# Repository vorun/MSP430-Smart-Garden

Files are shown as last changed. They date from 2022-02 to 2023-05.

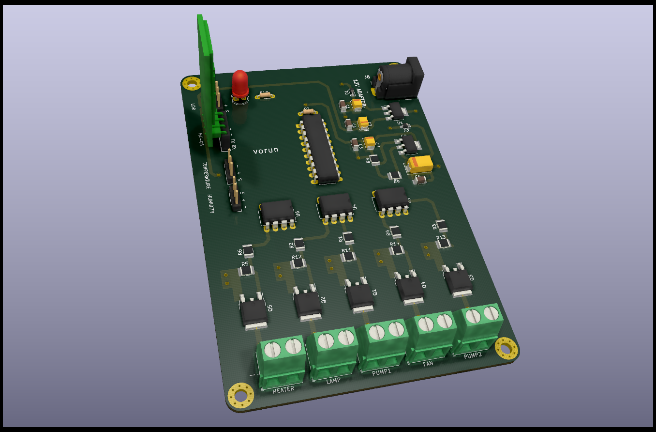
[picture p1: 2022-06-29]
PCB 3D View.png

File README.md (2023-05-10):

# MSP430-Smart-Garden

This project is a smart agricultural system based on C# using MSP430 microcontroller.

- Data coming from 3 sensors gets sent serially using bluetooth module from msp430 to computer and displayed at the
screen.

- Devices connected to msp430 which are lamp, fan, heater and 2 water pumps can be controlled from the
computer. Each button sends a different character and msp430 does operations acording to character it 
receives. Msp430 generates 3 different pwm signals to control fan and lamp for each setting which are 
low, medium and high. Heater can be oppened and closed. 2 water pumps can be oppened for 3 different 
amount times which are 3 seconds, 7 seconds and 10 seconds.

- Pin connections and circuit design/PCB of the project can be found at the 
"C# Based Smart Gardener Final PCB" folder.

For demo: https://www.youtube.com/watch?v=NzMayukbllw

Note
- Updated PCB with MOSFETs and gate drivers.

Orhun Dabak/Ahmet Özbaysar
PCB 3D View (1)
Picture_C#

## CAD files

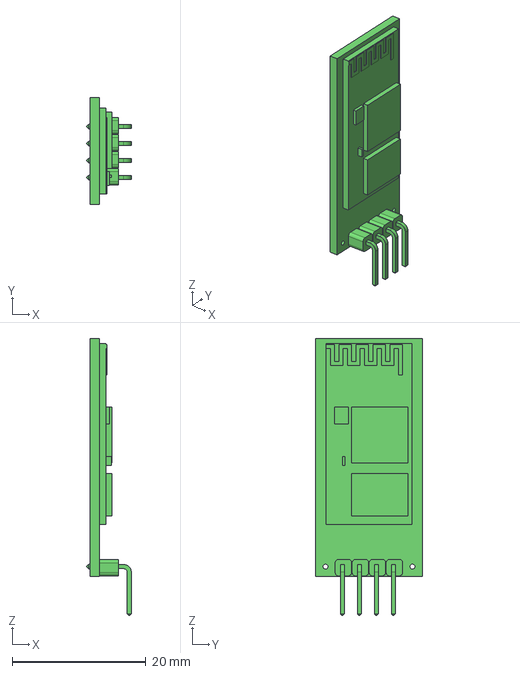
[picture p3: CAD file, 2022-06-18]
C# Based Smart Gardener Final PCB/hc 05/HC-05 Bluetooth Module.stp
6.68 x 16.0 x 41.4 mm

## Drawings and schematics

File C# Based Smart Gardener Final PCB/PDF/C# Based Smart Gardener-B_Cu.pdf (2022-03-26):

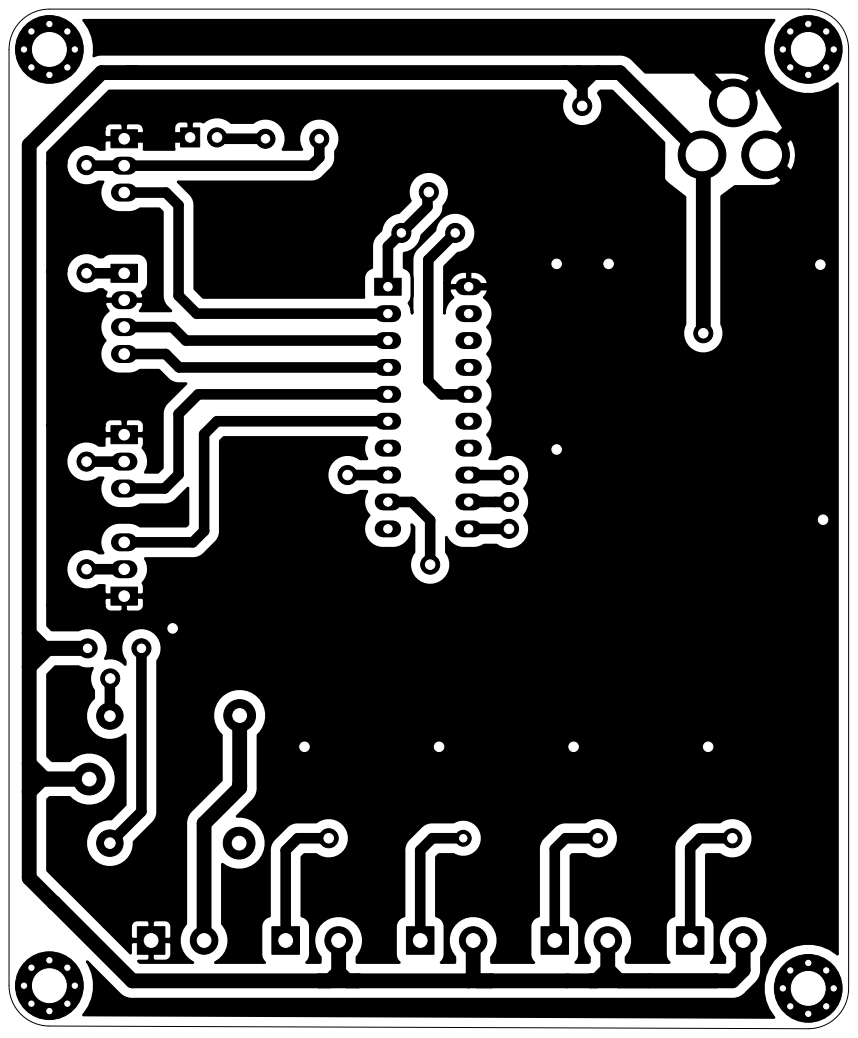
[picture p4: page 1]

File: C# Based Smart Gardener.kicad_pcb Sheet:
Id: 1/1 Title:

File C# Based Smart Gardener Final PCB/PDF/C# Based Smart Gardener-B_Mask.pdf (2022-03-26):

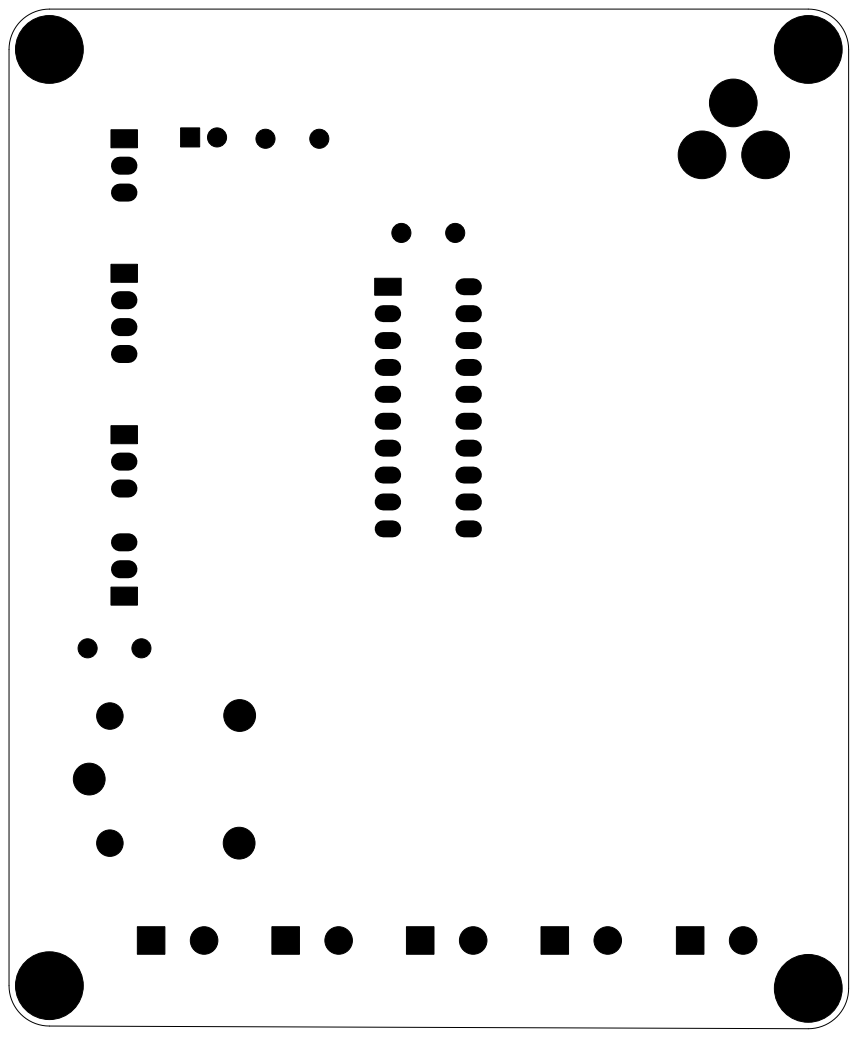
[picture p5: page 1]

File: C# Based Smart Gardener.kicad_pcb Sheet:
Id: 1/1 Title:

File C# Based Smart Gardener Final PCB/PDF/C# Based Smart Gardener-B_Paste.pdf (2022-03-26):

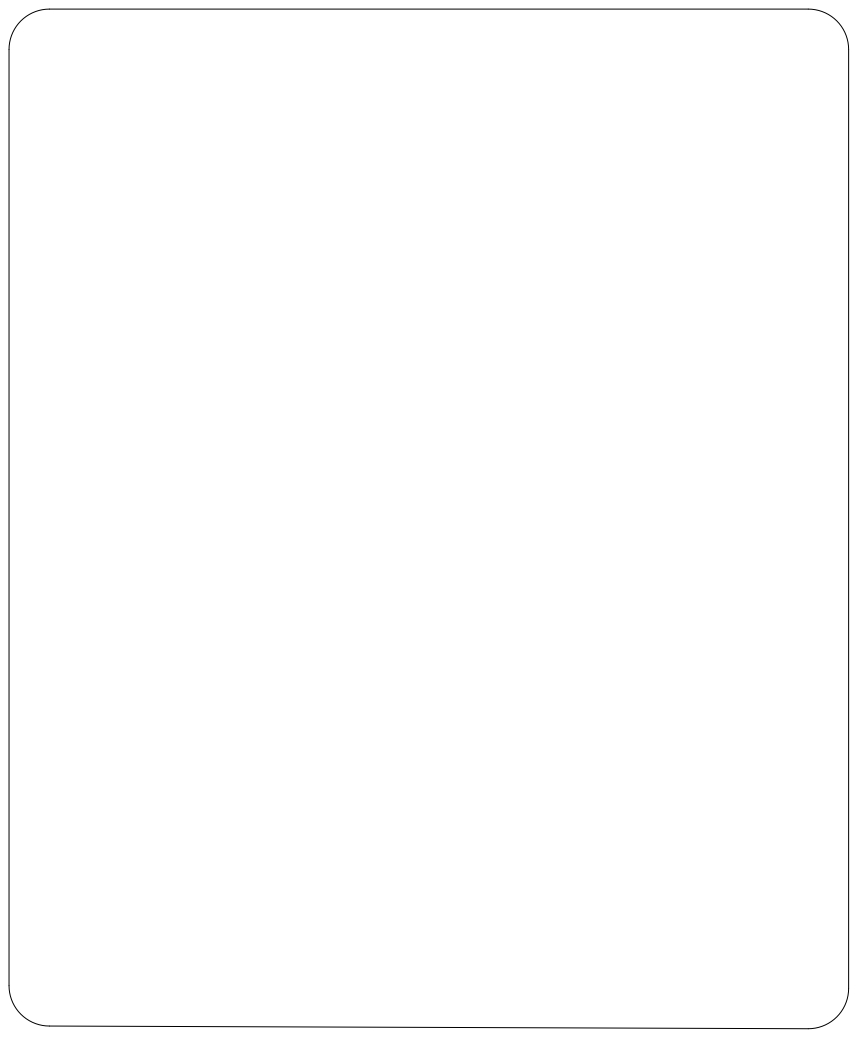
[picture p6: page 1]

File: C# Based Smart Gardener.kicad_pcb Sheet:
Id: 1/1 Title:

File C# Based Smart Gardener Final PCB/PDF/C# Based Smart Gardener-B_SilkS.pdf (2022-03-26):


File: C# Based Smart Gardener.kicad_pcb Sheet:
Id: 1/1 Title:

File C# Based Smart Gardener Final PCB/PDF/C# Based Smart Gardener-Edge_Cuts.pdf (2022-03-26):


File: C# Based Smart Gardener.kicad_pcb Sheet:
Id: 1/1 Title:

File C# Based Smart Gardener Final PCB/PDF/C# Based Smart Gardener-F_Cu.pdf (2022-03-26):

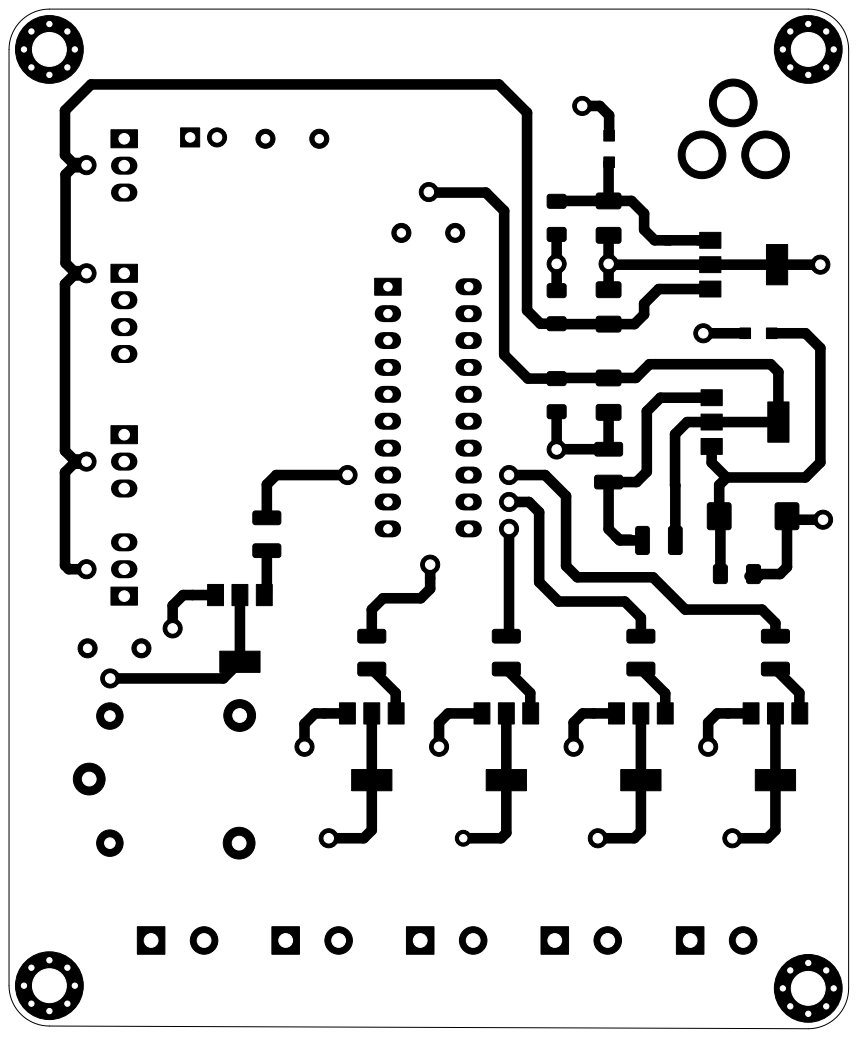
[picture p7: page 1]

File: C# Based Smart Gardener.kicad_pcb Sheet:
Id: 1/1 Title:

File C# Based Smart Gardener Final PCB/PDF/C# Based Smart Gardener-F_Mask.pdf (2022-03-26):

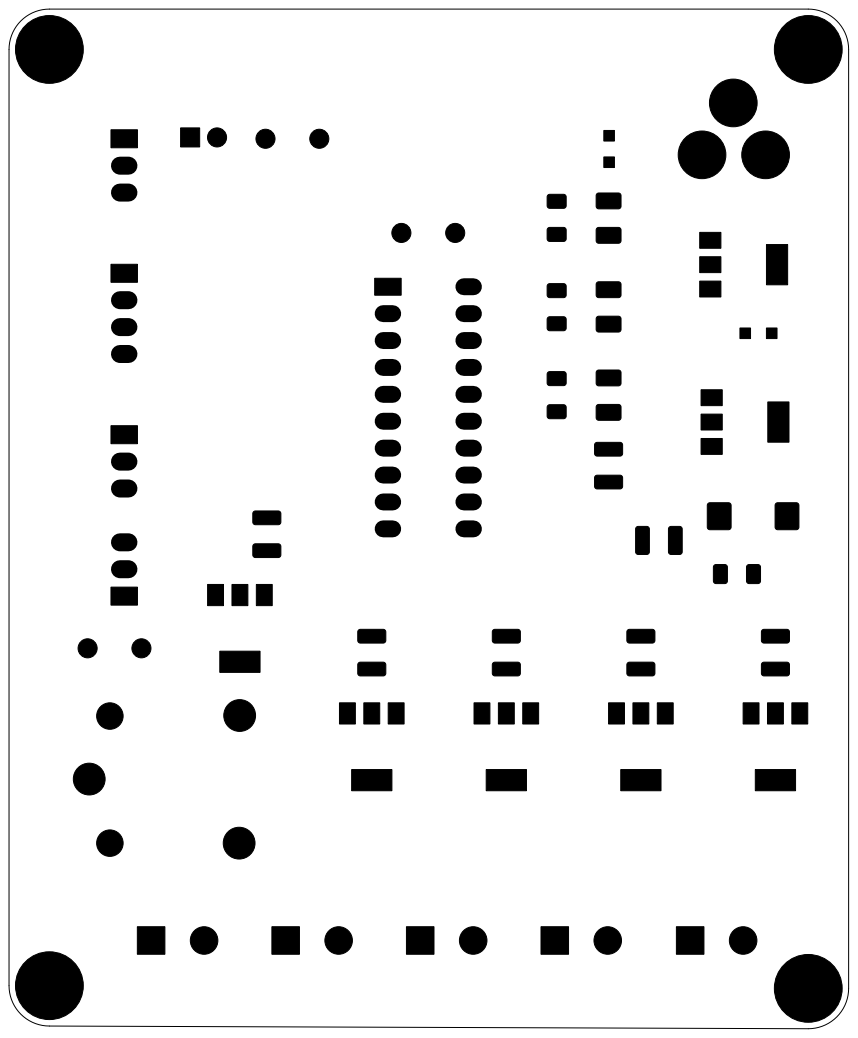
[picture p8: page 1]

File: C# Based Smart Gardener.kicad_pcb Sheet:
Id: 1/1 Title:

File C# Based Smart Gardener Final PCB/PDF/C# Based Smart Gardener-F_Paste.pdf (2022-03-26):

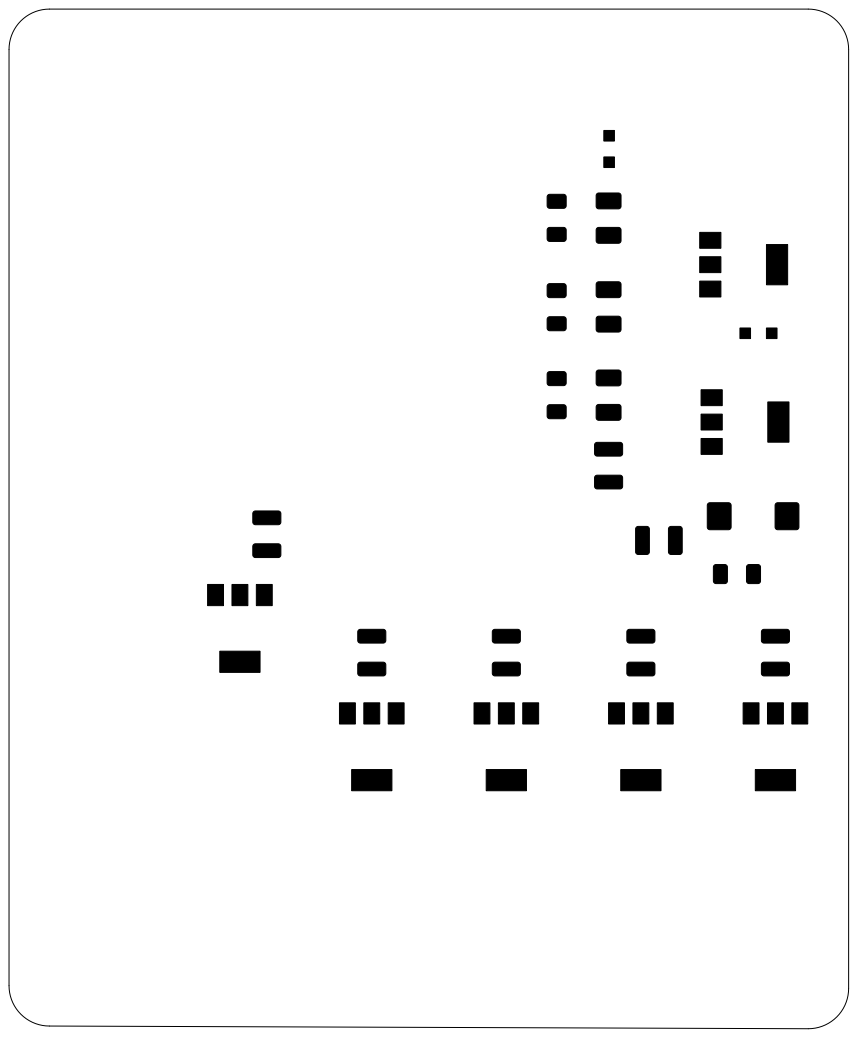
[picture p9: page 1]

File: C# Based Smart Gardener.kicad_pcb Sheet:
Id: 1/1 Title:

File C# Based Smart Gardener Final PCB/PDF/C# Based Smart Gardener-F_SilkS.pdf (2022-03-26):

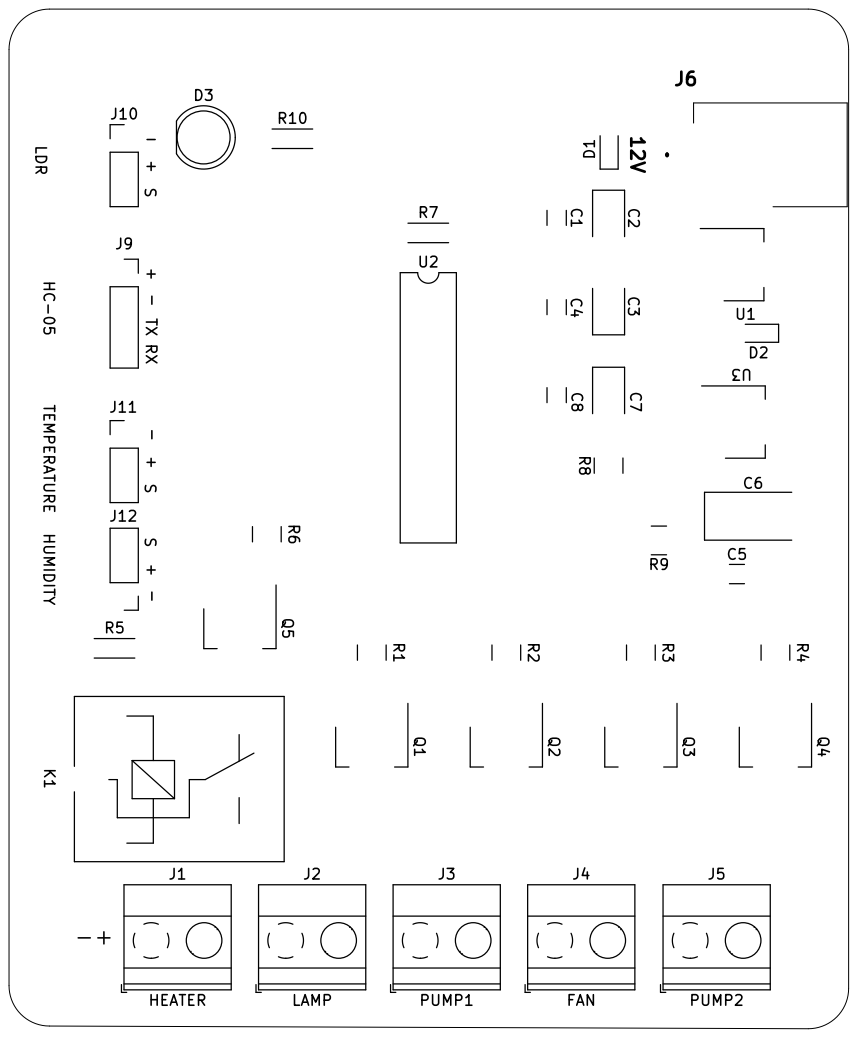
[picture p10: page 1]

File: C# Based Smart Gardener.kicad_pcb Sheet: - +S S +- - TX RX +S -+

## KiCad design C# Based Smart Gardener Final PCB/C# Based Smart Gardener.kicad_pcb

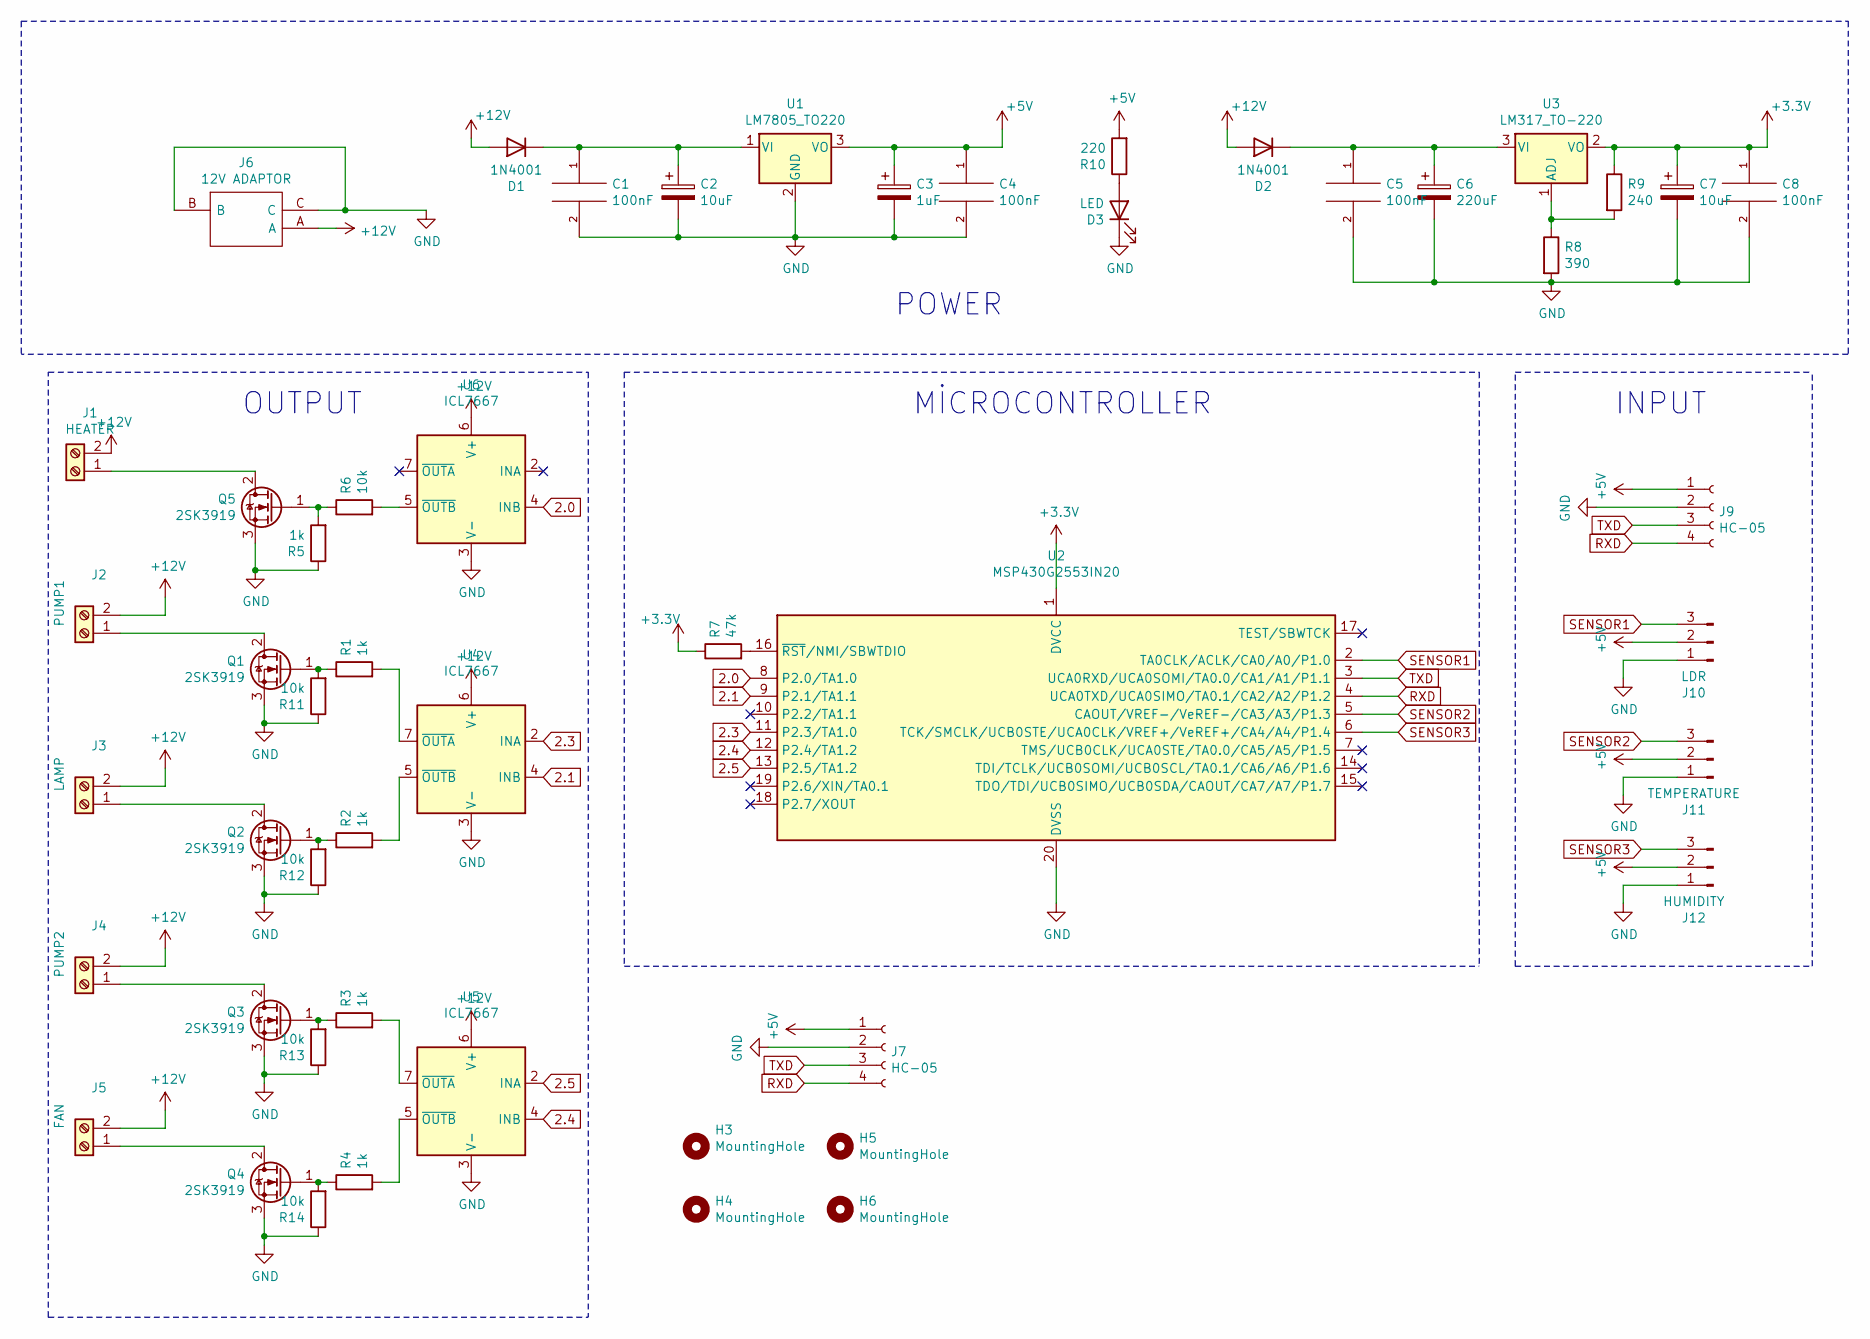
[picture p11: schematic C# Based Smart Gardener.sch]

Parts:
C1, C4, C5, C8: 100nF; C_1206_3216Metric_Pad1.33x1.80mm_HandSolder
C2, C7: 10uF; CP_EIA-3528-21_Kemet-B_Pad1.50x2.35mm_HandSolder
C3: 1uF; CP_EIA-3528-21_Kemet-B_Pad1.50x2.35mm_HandSolder
C6: 220uF; CP_EIA-7343-31_Kemet-D_Pad2.25x2.55mm_HandSolder
D1, D2: 1N4001; D_SOD-323_HandSoldering
D3: LED; LED_D5.0mm
H3, H4, H5, H6: MountingHole; MountingHole_3.2mm_M3_Pad_Via
J1: HEATER; TerminalBlock_Phoenix_MKDS-1,5-2_1x02_P5.00mm_Horizontal
J2: PUMP1; TerminalBlock_Phoenix_MKDS-1,5-2_1x02_P5.00mm_Horizontal
J3: LAMP; TerminalBlock_Phoenix_MKDS-1,5-2_1x02_P5.00mm_Horizontal
J4: PUMP2; TerminalBlock_Phoenix_MKDS-1,5-2_1x02_P5.00mm_Horizontal
J5: FAN; TerminalBlock_Phoenix_MKDS-1,5-2_1x02_P5.00mm_Horizontal
J6: 12V ADAPTOR; 163179PHEX; Manufacturer_Part_Number 163-179PH-EX; Mouser Part Number 163-179PH-EX
J7, J9: HC-05; PinSocket_1x04_P2.54mm_Vertical
J10: LDR; PinHeader_1x03_P2.54mm_Vertical
J11: TEMPERATURE; PinHeader_1x03_P2.54mm_Vertical
J12: HUMIDITY; PinHeader_1x03_P2.54mm_Vertical
Q1, Q2, Q3, Q4, Q5: 2SK3919; TO-252-2
R1, R2, R3, R4, R5: 1k; R_1210_3225Metric_Pad1.30x2.65mm_HandSolder
R6, R11, R12, R13, R14: 10k; R_1210_3225Metric_Pad1.30x2.65mm_HandSolder
R7: 47k; R_Axial_DIN0204_L3.6mm_D1.6mm_P5.08mm_Horizontal
R8: 390; R_1210_3225Metric_Pad1.30x2.65mm_HandSolder
R9: 240; R_1210_3225Metric_Pad1.30x2.65mm_HandSolder
R10: 220; R_Axial_DIN0204_L3.6mm_D1.6mm_P5.08mm_Horizontal
U1: LM7805_TO220; SOT-223-3_TabPin2
U2: MSP430G2553IN20; DIP-20_W7.62mm
U3: LM317_TO-220; SOT-223-3_TabPin2
U4, U5, U6: ICL7667; DIP-8_W7.62mm

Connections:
2.0: U2.8 (P2.0/TA1.0), U6.4 (INB)
2.1: U2.9 (P2.1/TA1.1), U4.4 (INB)
2.3: U2.11 (P2.3/TA1.0), U4.2 (INA)
2.4: U2.12 (P2.4/TA1.2), U5.4 (INB)
2.5: U2.13 (P2.5/TA1.2), U5.2 (INA)
+3V3: C7.1, C8.1, R7.1, R9.1, U2.1 (DVCC), U3.2 (VO)
+5V: C3.1, C4.1, J7.1, J9.1, J10.2, J11.2, J12.2, R10.2, U1.3 (VO)
+12V: D1.2 (A), D2.2 (A), J1.2, J2.2, J3.2, J4.2, J5.2, J6.A, U4.6 (V+), U5.6 (V+), U6.6 (V+)
GND: C1.2, C2.2, C3.2, C4.2, C5.2, C6.2, C7.2, C8.2, D3.1 (K), J6.B, J6.C, J7.2, J9.2, J10.1, J11.1, J12.1, Q1.3 (S), Q2.3 (S), Q3.3 (S), Q4.3 (S), Q5.3 (S), R5.1, R8.2, R11.1, R12.1, R13.1, R14.1, U1.2 (GND), U2.20 (DVSS), U4.3 (V-), U5.3 (V-), U6.3 (V-)
unnamed: C1.1, C2.1, D1.1 (K), U1.1 (VI)
unnamed: C5.1, C6.1, D2.1 (K), U3.3 (VI)
unnamed: D3.2 (A), R10.1
unnamed: J1.1, Q5.2 (D)
unnamed: J2.1, Q1.2 (D)
unnamed: J3.1, Q2.2 (D)
unnamed: J4.1, Q3.2 (D)
unnamed: J5.1, Q4.2 (D)
unnamed: Q1.1 (G), R1.1, R11.2
unnamed: Q2.1 (G), R2.1, R12.2
unnamed: Q3.1 (G), R3.1, R13.2
unnamed: Q4.1 (G), R4.1, R14.2
unnamed: Q5.1 (G), R5.2, R6.1
unnamed: R1.2, U4.7 (~OUTA)
unnamed: R2.2, U4.5 (~OUTB)
unnamed: R3.2, U5.7 (~OUTA)
unnamed: R4.2, U5.5 (~OUTB)
unnamed: R6.2, U6.5 (~OUTB)
unnamed: R7.2, U2.16 (~RST~/NMI/SBWTDIO)
unnamed: R8.1, R9.2, U3.1 (ADJ)
RXD: J7.4, J9.4, U2.4 (UCA0TXD/UCA0SIMO/TA0.1/CA2/A2/P1.2)
SENSOR1: J10.3, U2.2 (TA0CLK/ACLK/CA0/A0/P1.0)
SENSOR2: J11.3, U2.5 (CAOUT/VREF-/VeREF-/CA3/A3/P1.3)
SENSOR3: J12.3, U2.6 (TCK/SMCLK/UCB0STE/UCA0CLK/VREF+/VeREF+/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)
TXD: J7.3, J9.3, U2.3 (UCA0RXD/UCA0SOMI/TA0.0/CA1/A1/P1.1)

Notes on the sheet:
MİCROCONTROLLER
INPUT
OUTPUT
POWER

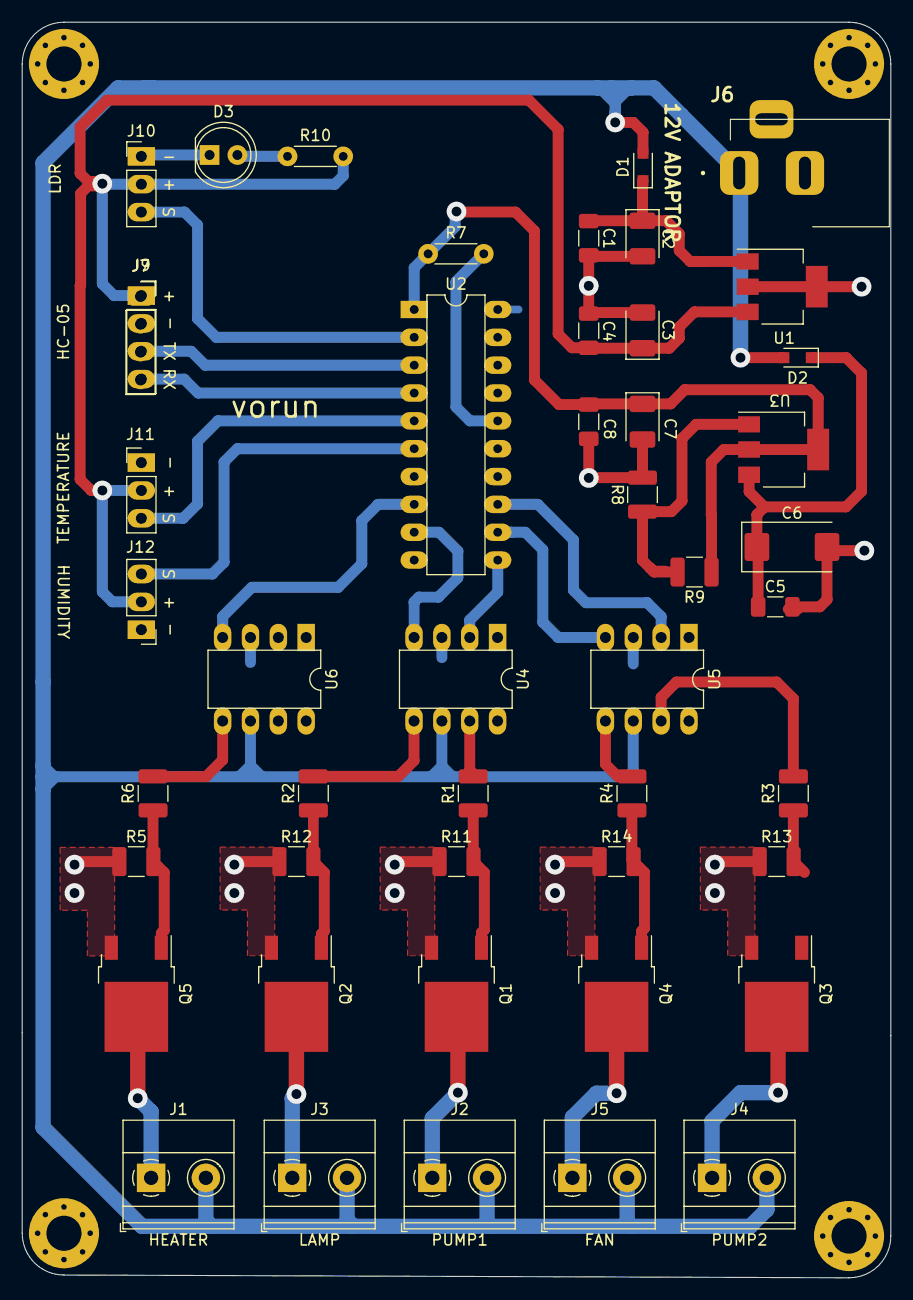
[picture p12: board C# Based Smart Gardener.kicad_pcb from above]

Board: 2 copper layers, 79.2 x 114.6 mm, 51 parts (0 on the bottom side), 34 nets.

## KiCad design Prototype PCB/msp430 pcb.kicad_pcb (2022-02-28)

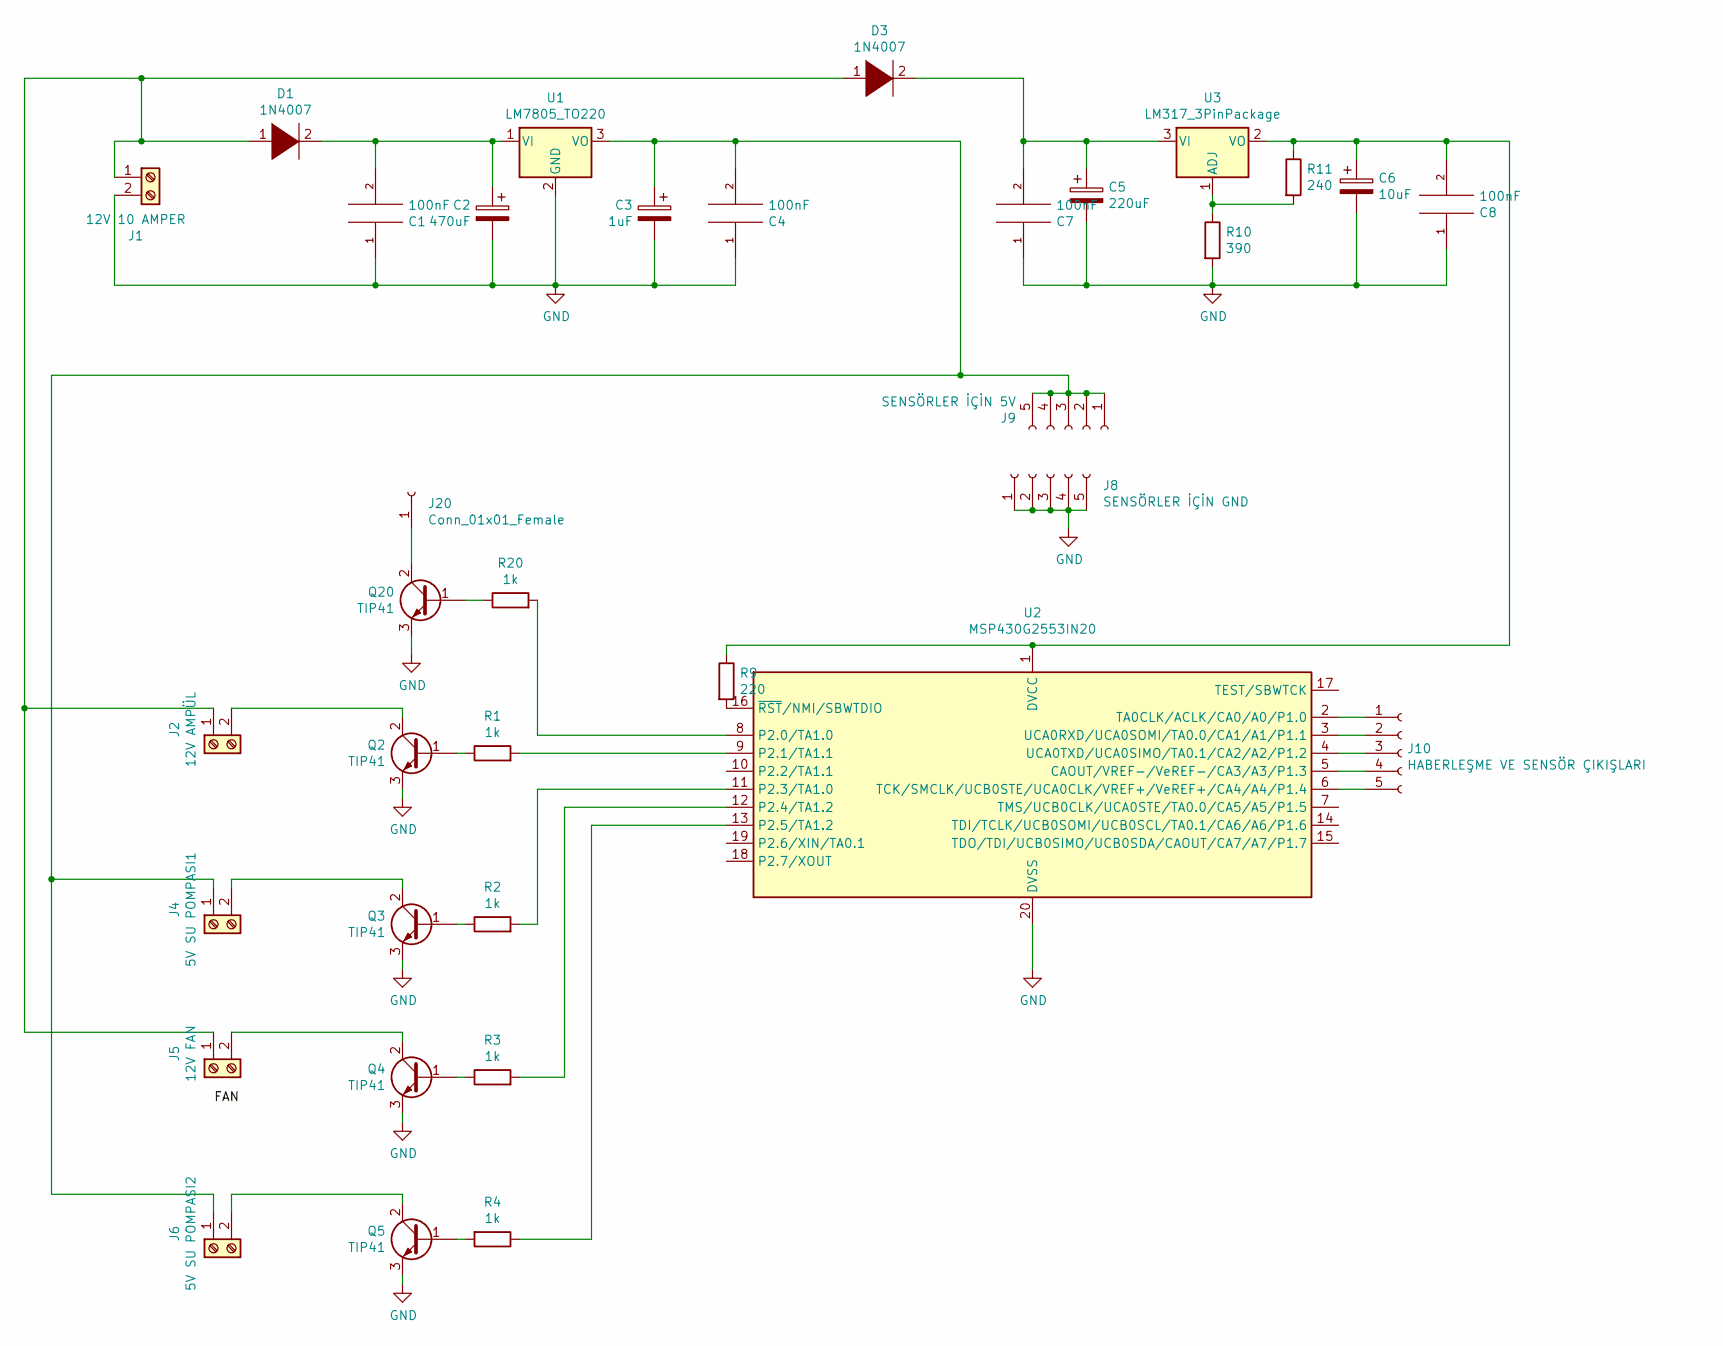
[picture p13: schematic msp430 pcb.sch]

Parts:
C1, C4, C7, C8: 100nF; CP_Radial_Tantal_D5.5mm_P5.00mm
C2: 470uF; CP_Radial_Tantal_D9.0mm_P5.00mm
C3: 1uF; CP_Radial_Tantal_D5.5mm_P5.00mm
C5: 220uF; CP_Radial_Tantal_D5.5mm_P5.00mm
C6: 10uF; CP_Radial_Tantal_D5.5mm_P5.00mm
D1: 1N4007; D_DO-41_SOD81_P7.62mm_Horizontal
D3: 1N4007; D_DO-41_SOD81_P10.16mm_Horizontal
J1: 12V 10 AMPER; TerminalBlock_Phoenix_MKDS-1,5-2_1x02_P5.00mm_Horizontal
J2: 12V AMPÜL; TerminalBlock_Phoenix_MKDS-1,5-2_1x02_P5.00mm_Horizontal
J4: 5V SU POMPASI1; TerminalBlock_Phoenix_MKDS-1,5-2_1x02_P5.00mm_Horizontal
J5: 12V FAN; TerminalBlock_Phoenix_MKDS-1,5-2_1x02_P5.00mm_Horizontal
J6: 5V SU POMPASI2; TerminalBlock_Phoenix_MKDS-1,5-2_1x02_P5.00mm_Horizontal
J8: SENSÖRLER İÇİN GND; PinHeader_1x05_P2.54mm_Vertical
J9: SENSÖRLER İÇİN 5V; PinHeader_1x05_P2.54mm_Vertical
J10: HABERLEŞME VE SENSÖR ÇIKIŞLARI; PinHeader_1x05_P2.54mm_Vertical
J20: Conn_01x01_Female; PinHeader_1x01_P2.54mm_Vertical
Q2, Q3, Q4, Q5, Q20: TIP41; TO-220-3_Vertical
R1, R2, R3, R4, R20: 1k; R_Axial_DIN0309_L9.0mm_D3.2mm_P12.70mm_Horizontal
R9: 220; R_Axial_DIN0309_L9.0mm_D3.2mm_P12.70mm_Horizontal
R10: 390; R_Axial_DIN0309_L9.0mm_D3.2mm_P12.70mm_Horizontal
R11: 240; R_Axial_DIN0309_L9.0mm_D3.2mm_P12.70mm_Horizontal
U1: LM7805_TO220; TO-220-3_Vertical
U2: MSP430G2553IN20; DIP-20_W7.62mm
U3: LM317_3PinPackage; TO-220-3_Vertical

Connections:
GND: C1.1, C2.2, C3.2, C4.1, C5.2, C6.2, C7.1, C8.1, J1.2, J8.1, J8.2, J8.3, J8.4, J8.5, Q2.3 (E), Q3.3 (E), Q4.3 (E), Q5.3 (E), Q20.3 (E), R10.2, U1.2 (GND), U2.20 (DVSS)
unnamed: C1.2, C2.1, D1.2 (A), U1.1 (VI)
unnamed: C3.1, C4.2, J4.1, J6.1, J9.1, J9.2, J9.3, J9.4, J9.5, U1.3 (VO)
unnamed: C5.1, C7.2, D3.2 (A), U3.3 (VI)
unnamed: C6.1, C8.2, R9.1, R11.1, U2.1 (DVCC), U3.2 (VO)
unnamed: D1.1 (K), D3.1 (K), J1.1, J2.1, J5.1
unnamed: J2.2, Q2.2 (C)
unnamed: J4.2, Q3.2 (C)
unnamed: J5.2, Q4.2 (C)
unnamed: J6.2, Q5.2 (C)
unnamed: J10.1, U2.2 (TA0CLK/ACLK/CA0/A0/P1.0)
unnamed: J10.2, U2.3 (UCA0RXD/UCA0SOMI/TA0.0/CA1/A1/P1.1)
unnamed: J10.3, U2.4 (UCA0TXD/UCA0SIMO/TA0.1/CA2/A2/P1.2)
unnamed: J10.4, U2.5 (CAOUT/VREF-/VeREF-/CA3/A3/P1.3)
unnamed: J10.5, U2.6 (TCK/SMCLK/UCB0STE/UCA0CLK/VREF+/VeREF+/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)
unnamed: J20.1, Q20.2 (C)
unnamed: Q2.1 (B), R1.1
unnamed: Q3.1 (B), R2.1
unnamed: Q4.1 (B), R3.1
unnamed: Q5.1 (B), R4.2
unnamed: Q20.1 (B), R20.1
unnamed: R1.2, U2.9 (P2.1/TA1.1)
unnamed: R2.2, U2.11 (P2.3/TA1.0)
unnamed: R3.2, U2.12 (P2.4/TA1.2)
unnamed: R4.1, U2.13 (P2.5/TA1.2)
unnamed: R9.2, U2.16 (~RST~/NMI/SBWTDIO)
unnamed: R10.1, R11.2, U3.1 (ADJ)
unnamed: R20.2, U2.8 (P2.0/TA1.0)

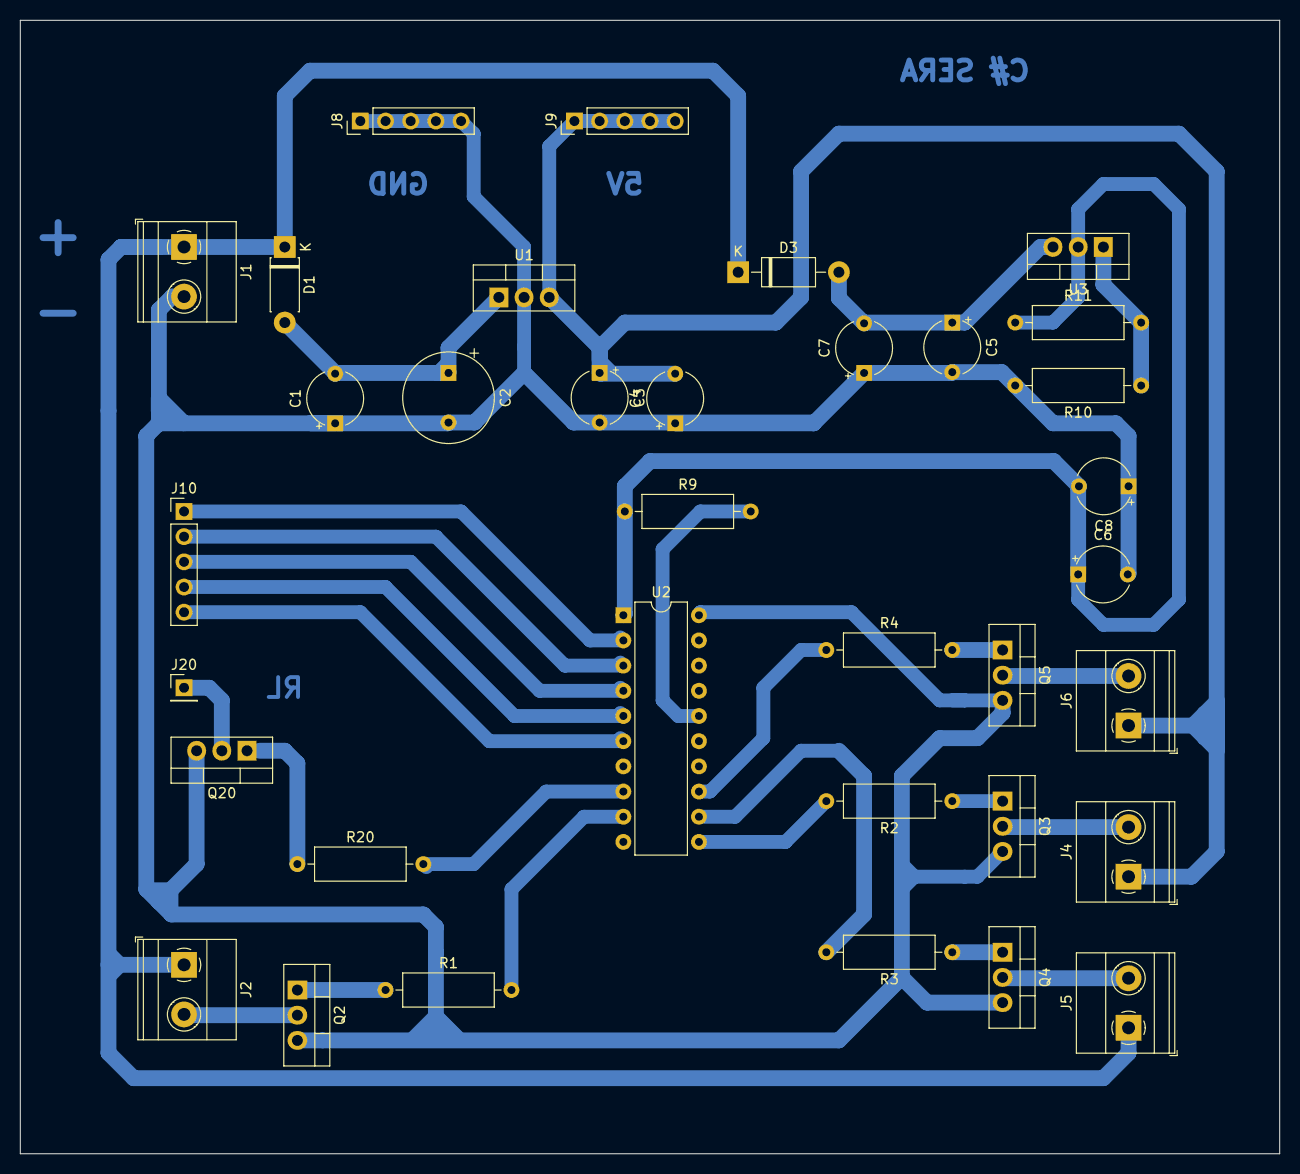
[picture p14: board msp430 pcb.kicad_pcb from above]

Board: 2 copper layers, 127.0 x 114.3 mm, 35 parts (0 on the bottom side), 28 nets.

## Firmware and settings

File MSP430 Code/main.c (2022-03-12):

#include <msp430.h>                         // Define libraries
#include <stdlib.h>
#include <stdio.h>
#include <string.h>
#include <math.h>

char vt_chara0[5];                          // Define arrays for storing analog values
char vt_chara1[5];
char vt_chara2[5];
char vt_chara3[5];
char vt_chara4[5];
char space[] = " ";

int input;                                  // Define 'input' to store incoming character inside uart buffer
unsigned int adc[5];                        // Define array to store string values of char arrays

void ser_output(char *str);                 // Function prototype

void main(void)
{
    WDTCTL = WDTPW | WDTHOLD;               // Stop watchdog timer

    BCSCTL1= CALBC1_1MHZ;                   // Set DCO to 1 MHz
    DCOCTL = CALDCO_1MHZ;

    P1SEL = BIT1|BIT2;                      // Select UART RX/TX function on P1.1,P1.2
    P1SEL2 = BIT1|BIT2;

    P2DIR = BIT0 + BIT1 + BIT3 + BIT4 + BIT5;       // P2.1 and P2.4 output
    P2SEL = BIT1 + BIT4;                            // Timer_A1
    P2OUT &= ~BIT0 + ~BIT3 + ~BIT5;

    TA1CCR0 = 1000-1;                   // PWM period
    TA1CCTL1 = OUTMOD_7;                //Mod7 reset/set
    TA1CCTL2 = OUTMOD_7;                //Moo7 reset/set
    TA1CTL = TASSEL_2 + MC_1;           // Timer SMCLK Modo UP

    UCA0CTL1 |= UCSWRST+UCSSEL_2;         // UART Clock -> SMCLK
    UCA0BR0 = 104;                       // Baud Rate Setting for 1MHz 9600
    UCA0BR1 = 0;                        // Baud Rate Setting for 1MHz 9600
    UCA0MCTL = UCBRS_1;                 // Baud Rate Setting for 1MHz 9600
    UCA0CTL1 &= ~UCSWRST;               // Initialize UART Module

    ADC10CTL1 = INCH_4 + ADC10DIV_0 + CONSEQ_3 + SHS_0;                         // ADC Channel (P1.4), divider,  Repeat sequence of channels, Sample-and-hold source select
    ADC10CTL0 = REFON + REF2_5V + SREF_1 + ADC10SHT_3 + MSC + ADC10ON;          // Referance on, Reference-generator voltage (0 - 1.5V, 1-2.5V), Select reference,
                                                                                // Sample-and-hold time, multiple sample and conversion, ADC10 ON
    ADC10AE0 = BIT4 + BIT3 + BIT0;                                              // P1.0, P1.3, P1.4 ADC options select
    ADC10DTC1 = 5;                                                              // Data Transfer Controller

    IE2 |= UCA0RXIE;                                                            // RX interrupt enabled
    __bis_SR_register(GIE);                                                     // General interrupt enabled

    while(1){
        ADC10CTL0 &= ~ENC;                                                      // Enable conversion -> disable
        while (ADC10CTL1 & BUSY);
        ADC10CTL0 |= ENC + ADC10SC;                                             // Enable conversion -> enable
        ADC10SA = (unsigned int)adc;

        ltoa(adc[4],vt_chara0,10); ltoa(adc[3],vt_chara1,10); ltoa(adc[2],vt_chara2,10);    // ltoa -> conversion long to string
        ltoa(adc[1],vt_chara3,10); ltoa(adc[0],vt_chara4,10);

        ser_output(vt_chara0);                        // Send analog 0 and space
        ser_output(space);

        ser_output(vt_chara1);
        ser_output(space);

        ser_output(vt_chara2);
        ser_output(space);

        ser_output(vt_chara3);                       // Send analog 3 and space
        ser_output(space);

        ser_output(vt_chara4);                       //Send analog 4 and space

        __delay_cycles(3000000);                     // 3s delay
    }
}

void ser_output(char *str) {                         // Data transmission function
    while(*str != 0){
        while (!(IFG2&UCA0TXIFG));
        UCA0TXBUF = *str++;
    }
}

#pragma vector=USCIAB0RX_VECTOR                     // RX interrupt vector
__interrupt void USCI0RX_ISR(void)
{

    input = UCA0RXBUF;
        switch(input)                               // Evaluating incoming data
        {
        case 'A':

            P2OUT|= BIT3;
            break;

        case 'B':

            P2OUT|= BIT3;
           break;

        case 'C':

            P2OUT &=~ BIT3;
           break;

        case 'D':

            P2OUT|= BIT5;
           break;

        case 'E':
            P2OUT|= BIT5;
            break;

        case 'F':
            P2OUT |= BIT5;
            break;

        case 'G':

            TA1CCR1 = 250;                  // PWM duty cycle
            break;

        case 'H':

            TA1CCR1 = 600;                  // PWM duty cycle
            break;

        case 'I':

            TA1CCR1 = 950;                  // PWM duty cycle
            break;

        case 'J':

            TA1CCR2 = 150;                  // PWM duty cycle
            break;

        case 'K':

            TA1CCR2 = 450;                  // PWM duty cycle
            break;

        case 'L':

            TA1CCR2 = 950;                  // PWM duty cycle
            break;

        case 'M':

            P2OUT |= BIT0;
            break;

        case 'N':

            P2OUT &=~ BIT0;
            break;

        case 'O':

            TA1CCR1 = 0;
            break;

        case 'P':

            TA1CCR2 = 0;
            break;

        case 'R':
            P2OUT &=~ BIT5;
            break;
    }

}

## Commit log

2022-03-26 PCB Update
    [C# Based Smart Gardener tht ragulators.kicad_pcb, C# Based Smart Gardener.kicad_pcb, C# Based Smart Gardener.sch]
2022-05-23 Create PCB 3D view.PNG
2022-05-24 Update PCB 3D view.PNG
2022-06-18 Update PCB
    [C# Based Smart Gardener.kicad_pcb, C# Based Smart Gardener.sch, HC-05 Bluetooth Module.stp]
2022-06-25 PCB Updated
    [C# Based Smart Gardener tht ragulators.kicad_pcb, C# Based Smart Gardener.kicad_pcb, C# Based Smart Gardener.sch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]
